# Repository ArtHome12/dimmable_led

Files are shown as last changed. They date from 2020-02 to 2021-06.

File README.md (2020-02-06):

# dimmable_led
Arduino lighting control using dimmable led driver. Control is carried out by button:
* A single click turns off the light or turns on with the previous brightness.
* A double click will turn on immediately at maximum brightness or, if the lamp is already shining, translates it to minimum brightness.
* Holding the button changes the brightness from minimum to maximum and back.
* If press and hold the button while the lamp is off, the lamp will turn on with a minimum brightness.
The state is stored in non-volatile memory. After external power up (or Arduino reset), the lamp is always off.

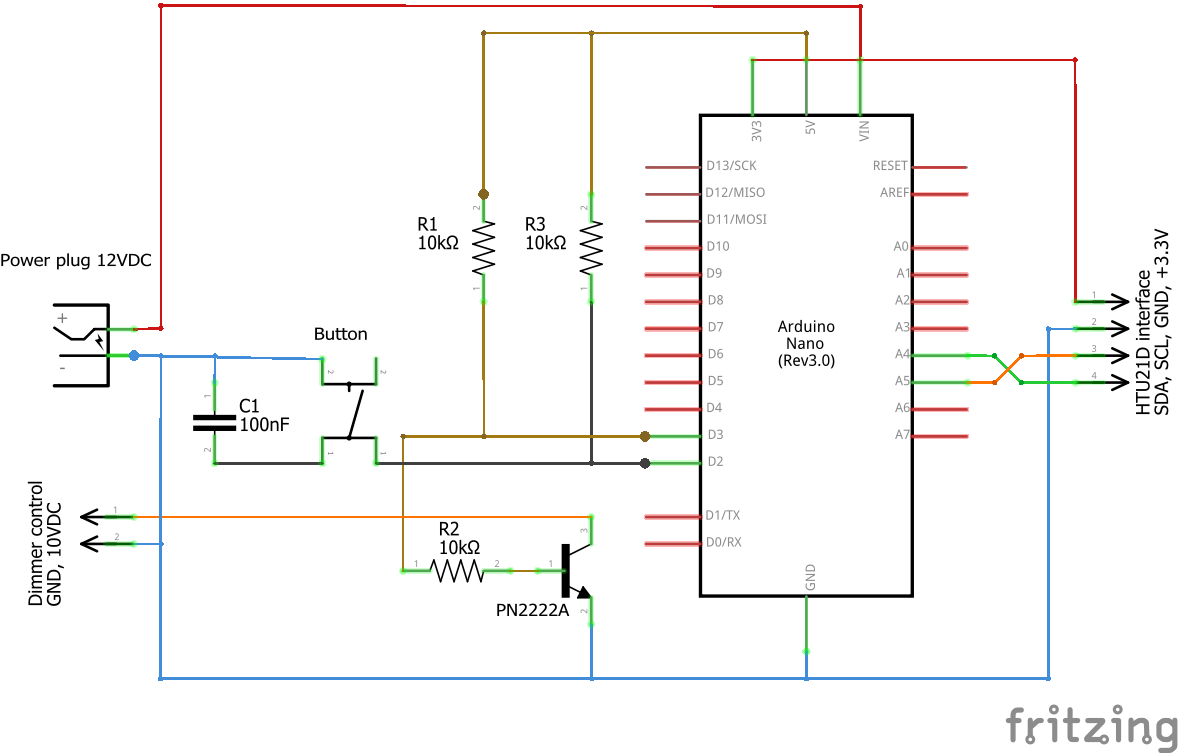
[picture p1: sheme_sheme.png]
sheme


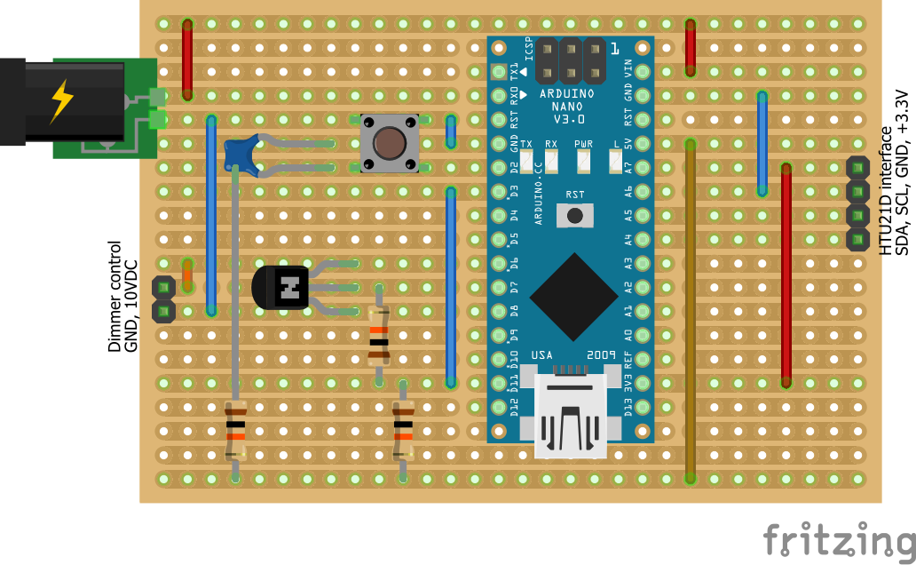
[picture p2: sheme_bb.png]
bread board


# LED driver
The driver has 3 contacts on one side: zero, phase 220 volts and ground. On the other, there are two pairs of contacts: the output (GND and 12VDC) for payload and the power control input:
1. When two control contacts are open, they have a potential of 10VDC and the driver gives maximum power (constantly 12VDC output).
2. When two control contacts are closed, that is, between them there is a potential of 0 volts, the driver does not give power (0 volts at the output).
3. When the intermediate voltage between the control contacts is between 0 and 10 volts, the PWM is working on the driver (from 8 to 12 volts an output square signal).

The driver power is declared 120W, under the cover it is already written 100W, in reality probably about 70W. As consumers - powerful LEDs on the 2mm aluminium plates.

Under the driver cover on the group of three capacitors there is a voltage of 12 VDC, from which arduino is powered. There are also 5VDC and 6.4VDC on smaller capacitors.

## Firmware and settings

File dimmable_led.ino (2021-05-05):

/* ===============================================================================
Управление диммируемым освещением.
1 February 2020.
----------------------------------------------------------------------------
Licensed under the terms of the GPL version 3.
http://www.gnu.org/licenses/gpl-3.0.html
Copyright (c) 2020 by Artem Khomenko _mag12@yahoo.com.
=============================================================================== */

#include <Bounce2.h>
#include <EEPROM.h>
#include <HTU21D.h>

// Для отладки - если определено, в Serial выводятся сообщения.
//#define DEBUG


// Адреса пинов
const int buttonPin = 2;  // номер входа, подключенный к кнопке
const int ledPin =  13;   // номер выхода светодиода
const int driverPin = 3;  // номер выхода на драйвер (транзистор).

// Поддерживаемые события
enum Events {
   eClick,                 // отжатие после щелчка
   eLongPress,             // долгое нажатие
   eLongPressFree,         // отпуск после долгого нажатия
   eDoubleClick            // отжатие после двойного щелчка
};

unsigned long previousMillis = 0;               // Момент последнего обновления
const unsigned long maxClickDelay = 500;        // Максимальное время для короткого щелчка, мс.
const unsigned long longPressFirstDelay = 1000; // Время до первого события bLongPress, мс.
const unsigned long longPressRepeatDelay = 10;  // Время между повторными событиями bLongPress, мс.
unsigned long previousClickMillis = 0;          // Время последнего короткого щелчка (для генерации двойного), мс.
const unsigned long temperatureControlDelay = 12000;  // Время между измерениями температуры, мс.
unsigned long temperatureControlMillis = 0;           // Время последнего измерения температуры, мс.

bool isBPressed = false;                        // Истина, когда кнопка нажата.

const int eepromAddrPWM = 0;        // Адрес для хранения в EEPROM признака завершения работы.
byte PWMLevel = 0;                  // Текущий уровень на ШИМ
const byte PWMLevelMinBright = 210; // Минимальная яркость (с запасом, светится до 223)
const byte PWMLevelHalfBright = 75;// Половинная яркость (с запасом, светится до 223)
bool increaseUp = true;             // Направление увеличения яркости при повторении LongPress.
bool powerOn = false;               // Включен или нет светодиод.

const float cWarningTemp = 50.0;    // Температура, при которой надо убавить яркость наполовину.
const float cCriticalTemp = 75.0;   // Температура, при которой надо убавить яркость на минимум.

// Для подавления дребезга
Bounce debouncer = Bounce();

HTU21D myHTU21D(HTU21D_RES_RH12_TEMP14);        // Интерфейс к датчику температуры и влажности.


void setup() {
   // Разгон частоты ШИМ. Пины D3 и D11 - 62.5 кГц https://alexgyver.ru/lessons/pwm-overclock/
#ifndef __INTELLISENSE__    // Обходим глюк интеллисенса, не понимающего include внутри ifdef.
   TCCR2B = 0b00000001; // x1
   TCCR2A = 0b00000011; // fast pwm
#endif

#if defined(DEBUG)
   // initialize serial communication:
   Serial.begin(115200);
   Serial.println("Start...");
#endif

   // Прочитаем прежнее значение яркости из EEPROM
   PWMLevel = EEPROM.read(eepromAddrPWM);

   // Пин на драйвер, сразу гасим лампу.
   pinMode(driverPin, OUTPUT);
   analogWrite(driverPin, 255);

   // инициализируем пин, подключенный к светодиоду, как выход
   pinMode(ledPin, OUTPUT);
   // инициализируем пин, подключенный к кнопке с защитой от дребезга.
   debouncer.attach(buttonPin, INPUT_PULLUP);

   // Датчик температуры.
   myHTU21D.begin();

   // Пропускаем возможный дребезг из-за включения.
   delay(600);
   debouncer.update();
}

void loop() {

   // Пропускаем дребезг.
   debouncer.update();

   // Текущее время.
   unsigned long currentMillis = millis();

   // считываем значения с входа кнопки
   bool bCurState = debouncer.read() == LOW;

   // Для удобства.
   unsigned long deltaTime = currentMillis - previousMillis;

   // Если произошло изменение состояния кнопки
   if (bCurState != isBPressed) {
      // Сохраняем новое состояние.
      isBPressed = bCurState;

      // Если кнопка была отжата.
      if (!isBPressed) {
         // Если кнопка была отжата быстро, значит произошёл щелчок.
         if (deltaTime < maxClickDelay) {
            // Отправляем событие либо щелчок либо двойной щелчок.
            event(currentMillis - previousClickMillis < longPressFirstDelay ? eDoubleClick : eClick);

            // Сохраняем время щелчка для выявления двойного щелчка.
            previousClickMillis = currentMillis;
         } else {
            // Если кнопка была отжата после долговременного нажатия.
            event(eLongPressFree);
         }
      }
   } else {
      // Если состояние не менялось.

      // Если кнопка в нажатом состоянии и прошло достаточно времени, надо посылать долгое нажатие.
      if (isBPressed) {
         if (deltaTime > longPressFirstDelay) {
            event(eLongPress);

            // Откорректируем время так, чтобы повторные длинные нажатия происходили быстро.
            previousMillis = currentMillis - longPressFirstDelay + longPressRepeatDelay;
         }
      } else {
         // Если кнопка в отжатом состоянии, сбрасываем время.
         previousMillis = currentMillis;
      }
   }

   // Контроль температуры
   if (currentMillis - temperatureControlMillis > temperatureControlDelay) {

      // Сохраним время текущего контроля температуры.
      temperatureControlMillis = currentMillis;

      // Прочитаем температуру с датчика (+-0.3C).
      float temp = myHTU21D.readTemperature();

      // Определим максимально допустимую яркость.
      byte maxAllowedBright = temp > cCriticalTemp ? PWMLevelMinBright : (temp > cWarningTemp ? PWMLevelHalfBright : 0);

      // Ограничим максимальную яркость.
      if (PWMLevel < maxAllowedBright)
         analogWrite(driverPin, maxAllowedBright);

   #if defined(DEBUG)
      Serial.print("Temperature ");   Serial.print(temp);
      Serial.print("C, maxAllowedBright ");   Serial.print(maxAllowedBright);
      Serial.print(" PWMLevel ");   Serial.println(PWMLevel);
   #endif
}


   // Индикация на светодиоде.
   digitalWrite(ledPin, isBPressed ? HIGH : LOW);
}

void event(Events bCommand) {
   switch (bCommand) {
      case eClick:
         #if defined(DEBUG)
            Serial.println("Click");
         #endif

         // Переключим освещение.
         powerOn = !powerOn;
         if (powerOn) {
            // Для гарантированного включения должна быть яркость не ниже минимальной.
            PWMLevel = PWMLevel > PWMLevelMinBright ? PWMLevelMinBright : PWMLevel;

            // После любого переключения при удержании кнопки яркость сначала увеличивается.
            increaseUp = false;
         } else
            // Выключение.
            PWMLevel = 255;

         // Управляем драйвером.
         analogWrite(driverPin, PWMLevel);
         EEPROM.write(eepromAddrPWM, PWMLevel);
      break;

      case eLongPress:
         // Если лимпа выключена, надо начать с минимальной яркости.
         if (!powerOn) {
            PWMLevel =  PWMLevelMinBright;
            increaseUp = false;
            powerOn = true;
            analogWrite(driverPin, PWMLevel);

            // Задержка, чтобы человек успел отреагировать на включение и убрать палец.
            delay(longPressFirstDelay);
            break;
         }

         // Изменяем значение уровня.
         if (increaseUp) {
            if (PWMLevel == 255) {
               PWMLevel = 254;
               increaseUp = false;
            } else {
               PWMLevel++;
            }
         } else {
            if (PWMLevel == 0) {
               PWMLevel = 1;
               increaseUp = true;
            } else {
               PWMLevel--;
            }
         }

         // Выдаём управляющий сигнал - за счёт перебора значений ниже минимальной яркости будет удобная пауза.
         #if defined(DEBUG)
            Serial.print("PWM Level ");    Serial.println(int(PWMLevel));
         #endif
         analogWrite(driverPin, PWMLevel > PWMLevelMinBright ? PWMLevelMinBright : PWMLevel);

      break;

      case eLongPressFree:
         #if defined(DEBUG)
            Serial.println("Store PWM");
         #endif
         EEPROM.write(eepromAddrPWM, PWMLevel);
      break;

      default: // eDoubleClick
         #if defined(DEBUG)
            Serial.println("Double click");
         #endif
         // Если лампа включена к повторному щелчку, т.е. была выключена при первом щелчке, включим её с максимальной яркостью
         if (powerOn) {
            PWMLevel = 0;
         } else {
            // Если лампа выключена, приглушим её до минимальной яркости
            PWMLevel =  PWMLevelMinBright;
            increaseUp = false;
            powerOn = true;
         }

         analogWrite(driverPin, PWMLevel);
         EEPROM.write(eepromAddrPWM, PWMLevel);
      break;
   }
}

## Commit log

2020-02-04 PWM level
2020-02-05 Version 1
    [sheme.fzz]
2020-02-06 Update sheme
    [sheme.fzz]
2020-02-07 Add anoters resistor
    [sheme.fzz]
2020-02-09 Delay instead turn off when change of brightness
    [layout.fzz]
2020-02-11 Final release
    [layout.fzz]
2020-02-13 Custom PWM
2020-02-13 Revert "Custom PWM"
    This reverts commit c65afcb5d254085ef7a6e31bb8e1943b0d26a841.
    [dimmable_led.ino]
2020-02-17 Fix turn on when powering
    [dimmable_led.ino]
2020-02-17 Add delay to prevent button bounce
    [dimmable_led.ino]
2020-03-20 Temperature sensor support
2021-06-14 Pull up button by external resistor
